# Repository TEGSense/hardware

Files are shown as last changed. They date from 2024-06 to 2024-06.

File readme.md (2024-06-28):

# TEG Sense Board

This is a thermoelectric generator (TEG) boost converter used to power a connected battery or capacitor to periodically operate a microcontroller reading from a biometric sensor to compute blood oxygen saturation. That was a big sentence!

This is the board version used in the published paper, revision 3 of the rigid prototypes.
It is used in conjunction with the [SpO2 board](https://github.com/TEGSense/hardware-spo2).
The board has a few bugs, so it's recommended to start with the [flex version](https://github.com/TEGSense/hardware-flex), even if you're not going to use a flex PCB.

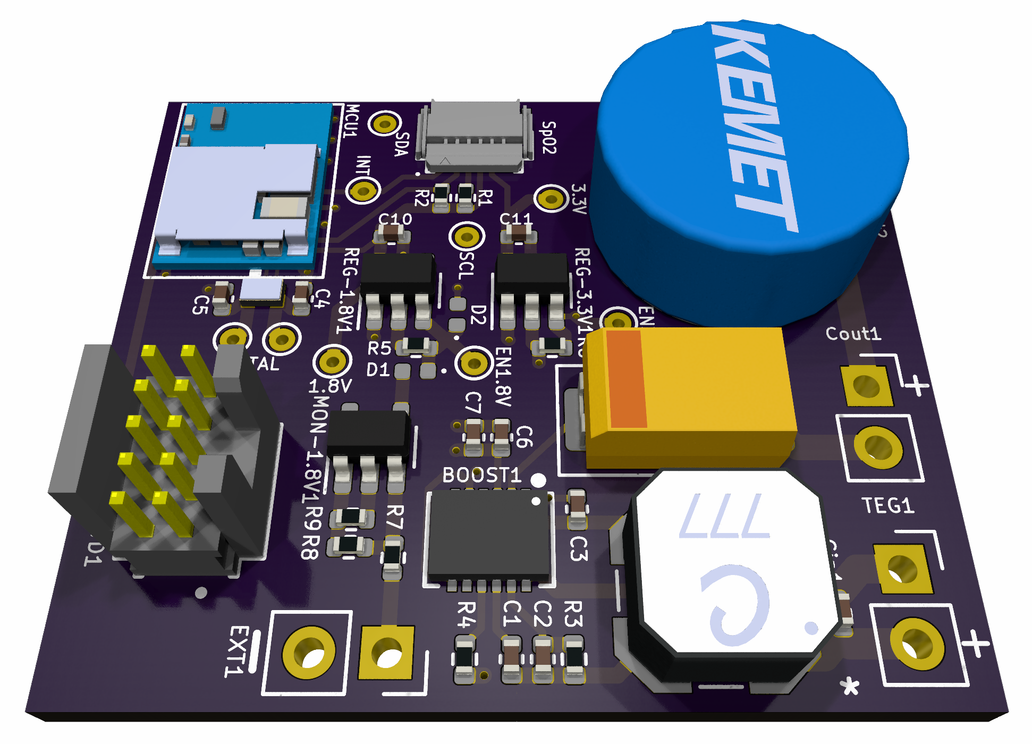
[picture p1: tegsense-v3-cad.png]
CAD rendering


## License

Shield: [][cc-by-sa]

This work is licensed under a
[Creative Commons Attribution-ShareAlike 4.0 International License][cc-by-sa].

[][cc-by-sa]

[cc-by-sa]: http://creativecommons.org/licenses/by-sa/4.0/
[cc-by-sa-image]: https://licensebuttons.net/l/by-sa/4.0/88x31.png
[cc-by-sa-shield]: https://img.shields.io/badge/License-CC%20BY--SA%204.0-lightgrey.svg

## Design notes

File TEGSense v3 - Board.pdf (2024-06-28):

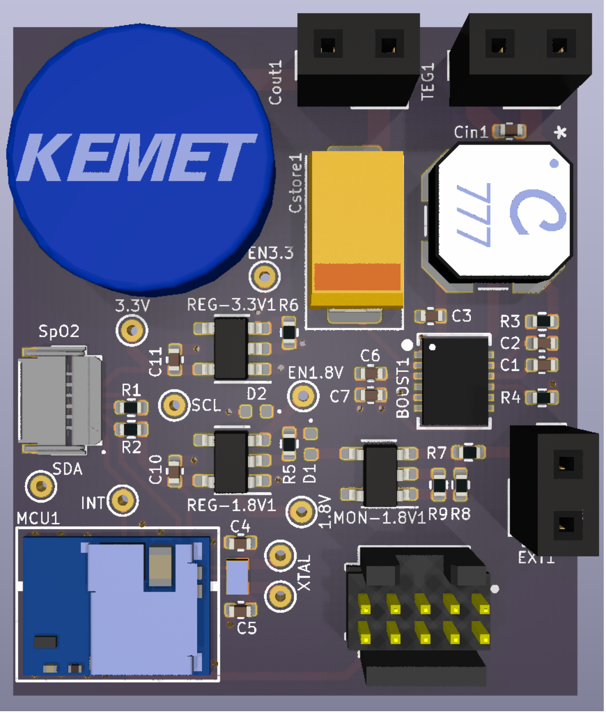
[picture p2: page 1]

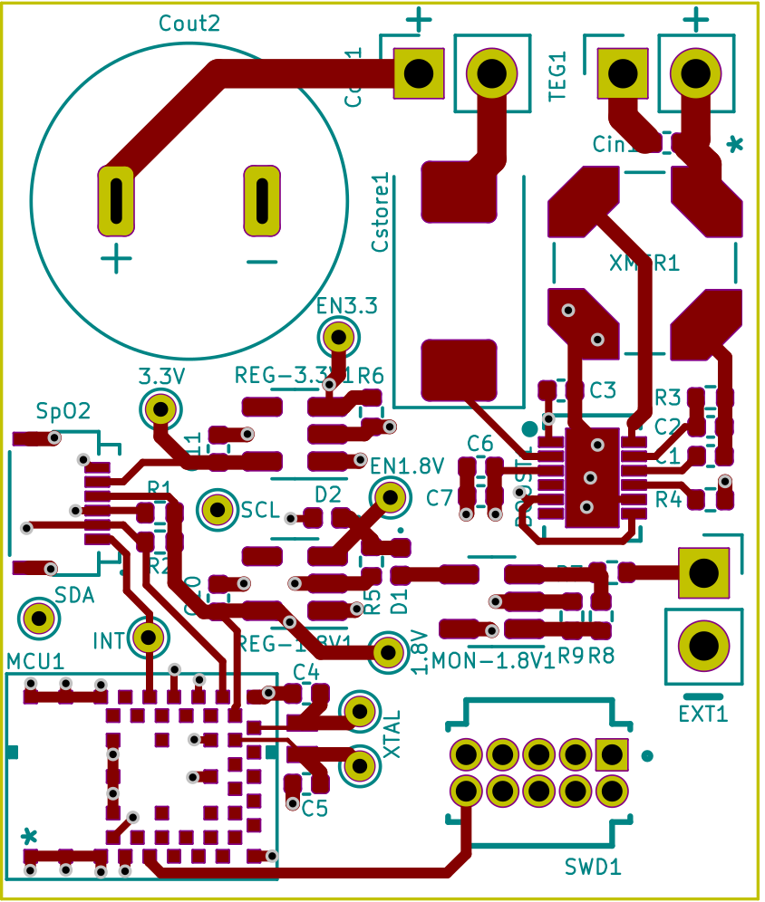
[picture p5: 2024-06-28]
TEGSense v3 - PCB Top.png

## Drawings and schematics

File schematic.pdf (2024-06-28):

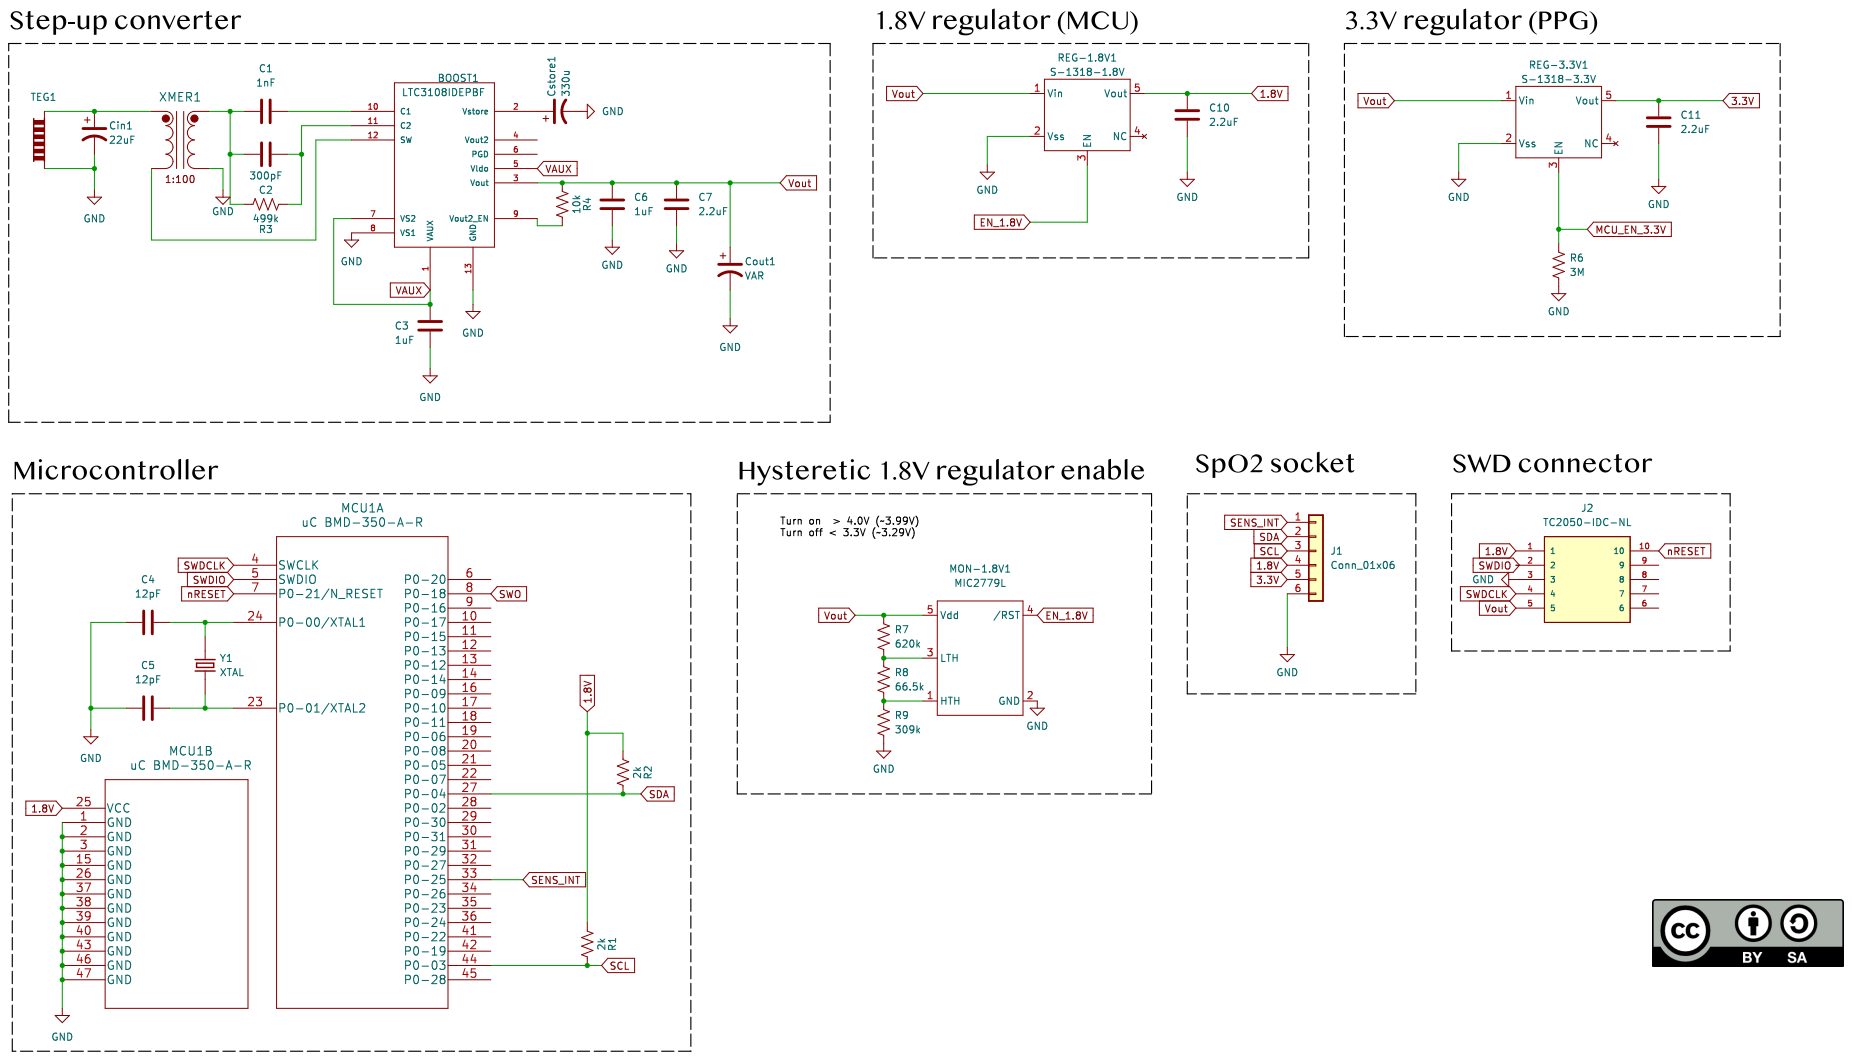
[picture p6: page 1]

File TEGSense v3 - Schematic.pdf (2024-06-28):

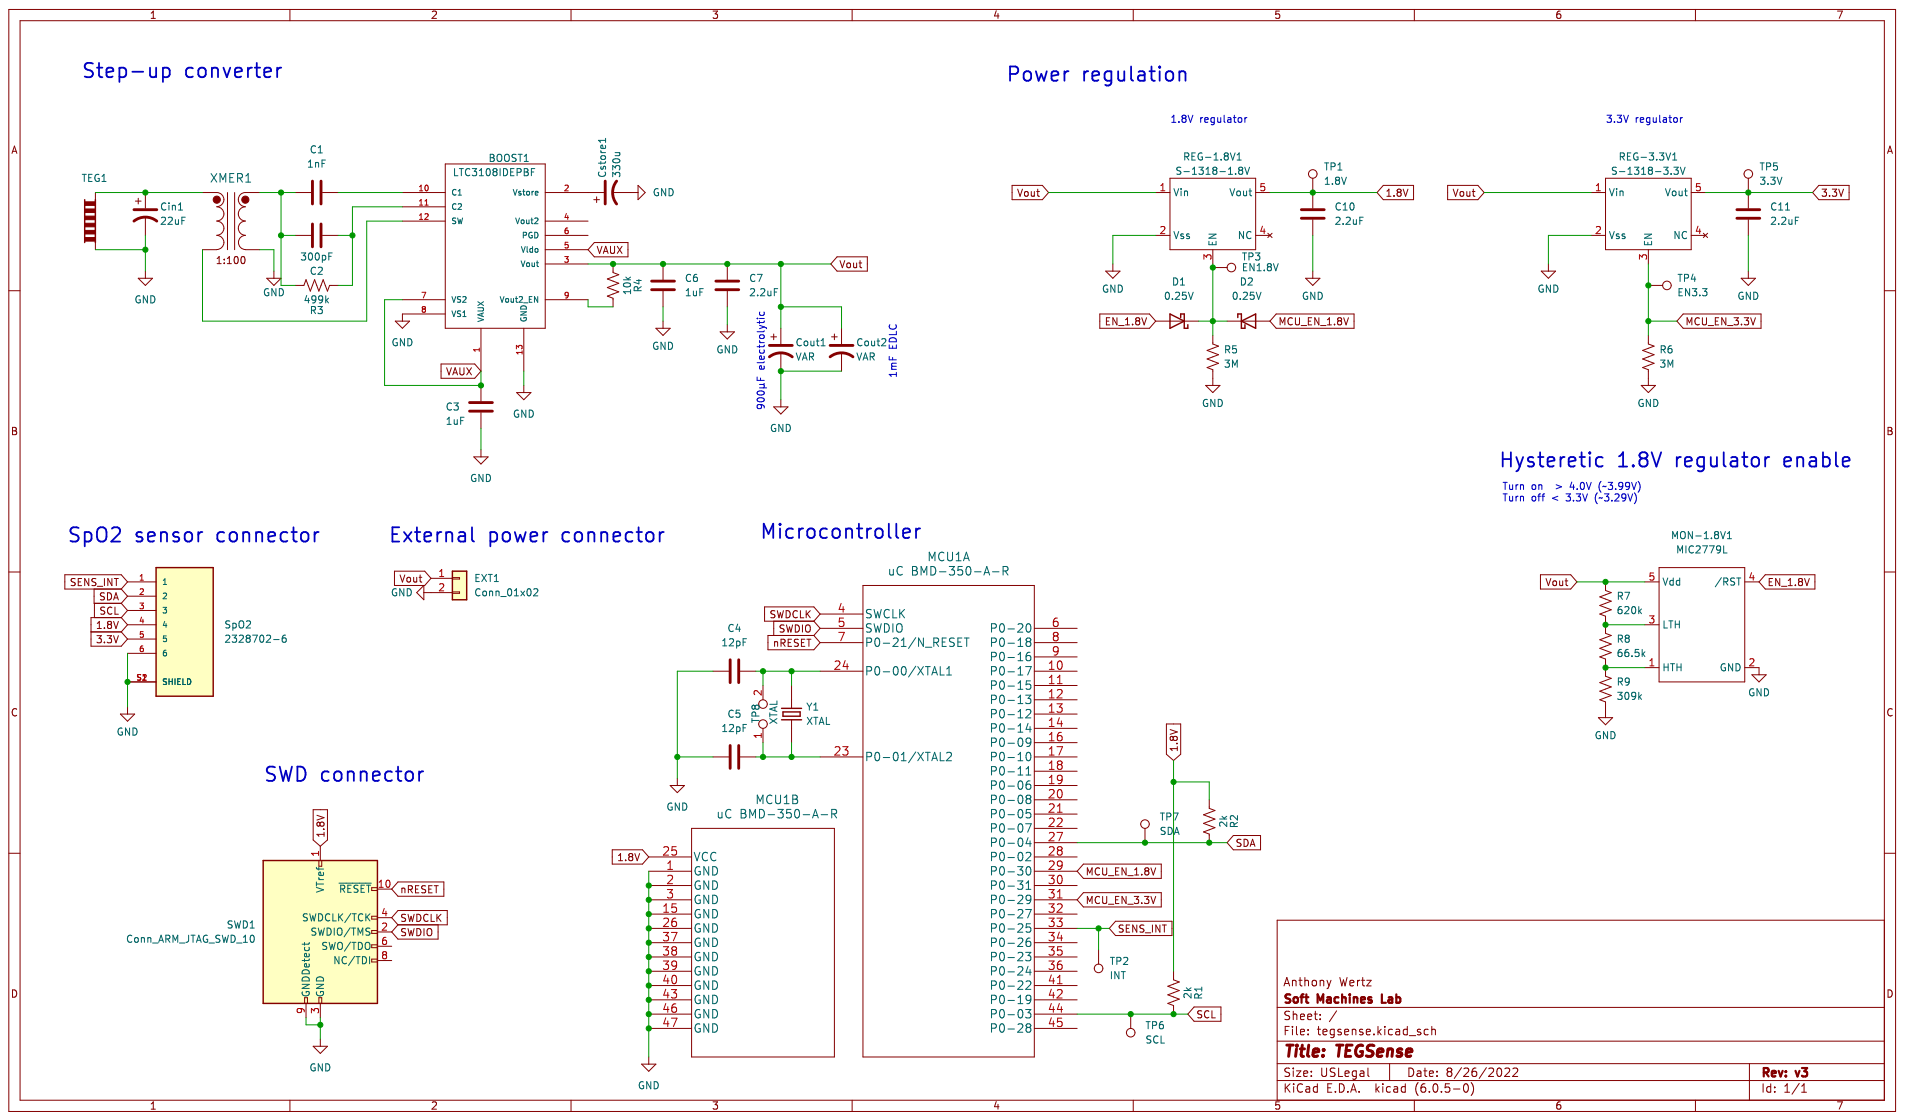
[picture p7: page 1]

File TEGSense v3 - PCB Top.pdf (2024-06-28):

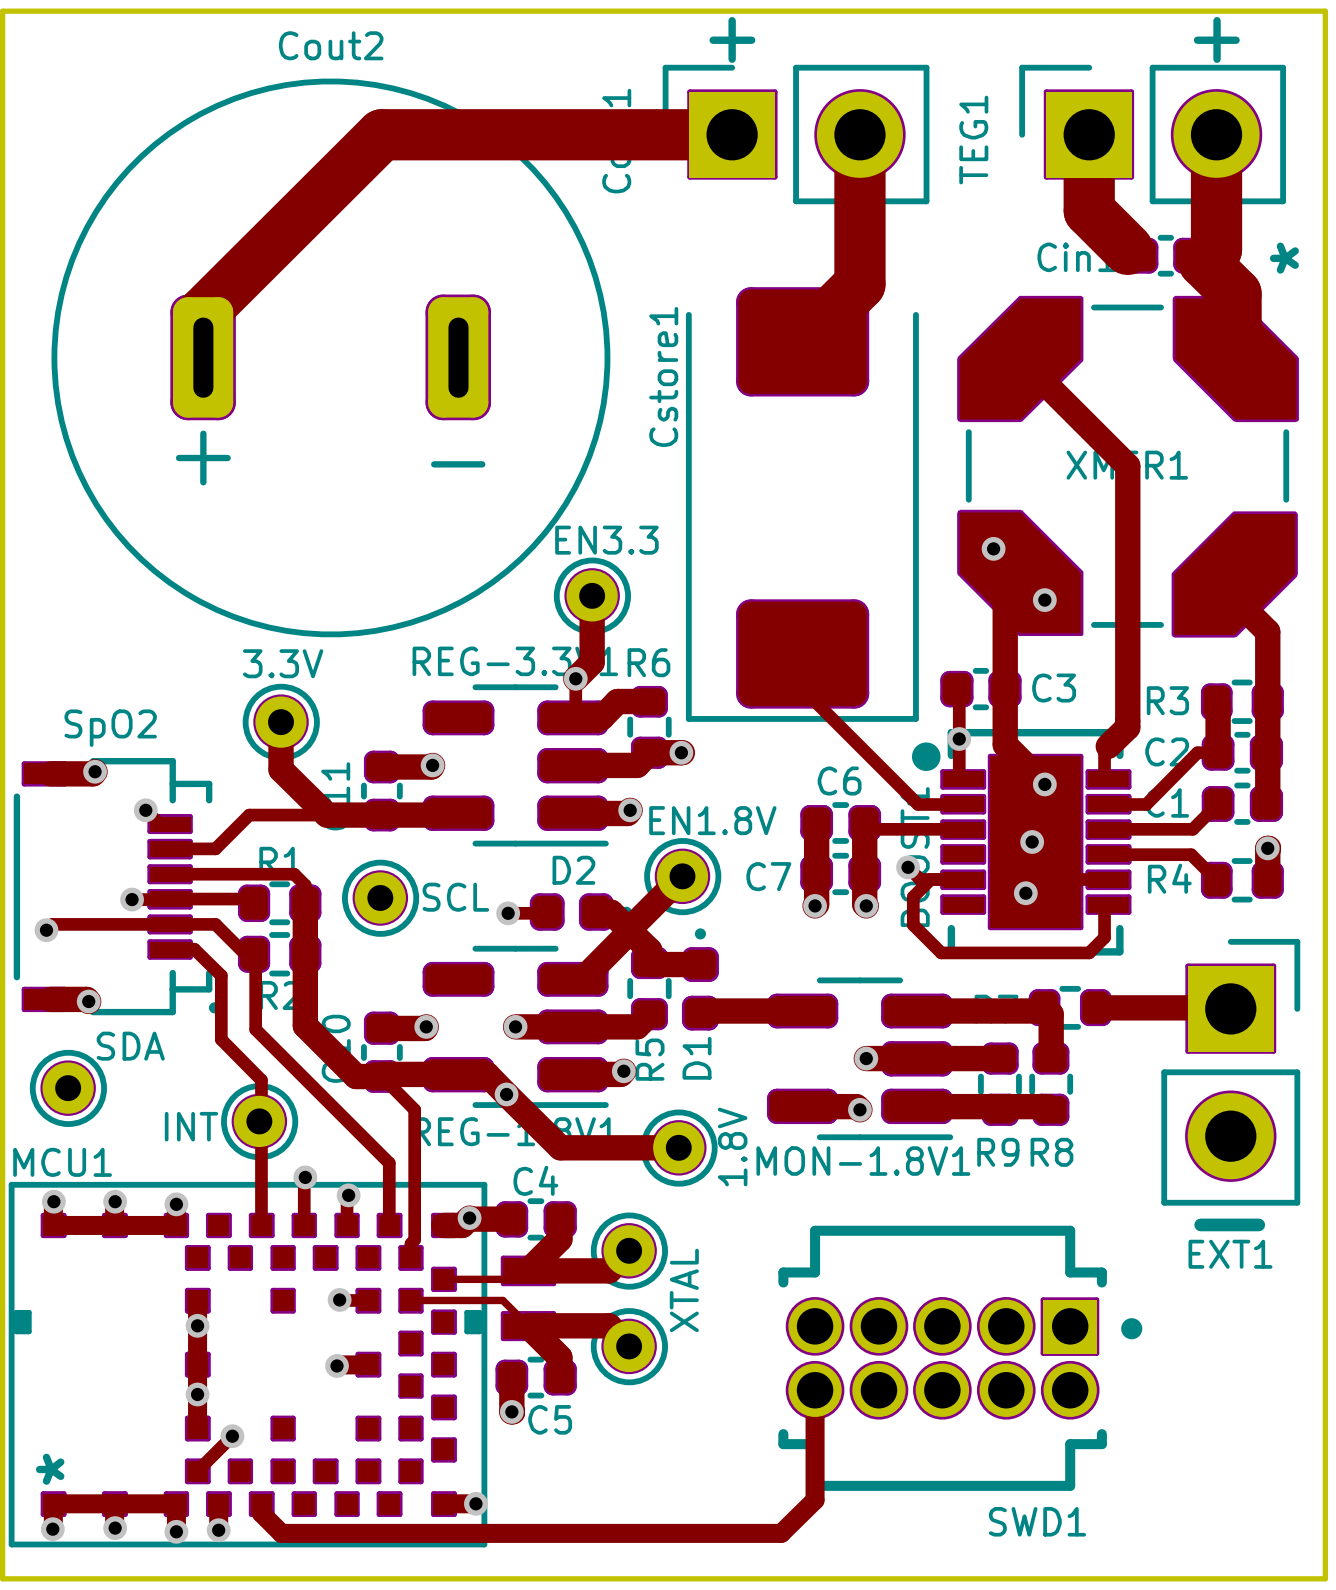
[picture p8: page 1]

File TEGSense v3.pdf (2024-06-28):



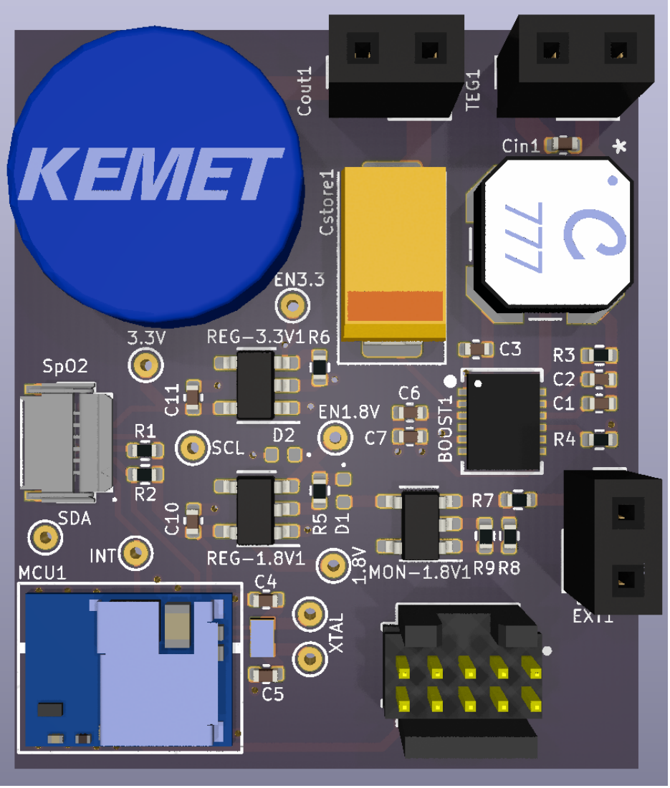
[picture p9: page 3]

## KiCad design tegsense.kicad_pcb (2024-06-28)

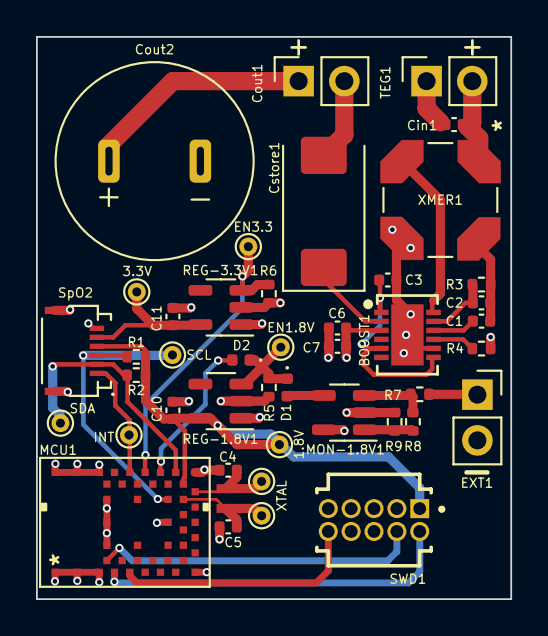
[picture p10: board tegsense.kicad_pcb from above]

Board: 4 copper layers, 26.4 x 31.2 mm, 43 parts (0 on the bottom side), 26 nets.

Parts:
BOOST1: LTC3108IDEPBF; DFN-12_DE
C1: 1nF; C_0402_1005Metric
C2: 300pF; C_0402_1005Metric
C3, C6: 1uF; C_0402_1005Metric
C4, C5: 12pF; C_0402_1005Metric
C7, C10, C11: 2.2uF; C_0402_1005Metric
Cin1: 22uF; C_0402_1005Metric
Cout1: VAR; PinSocket_1x02_P2.54mm_Vertical
Cout2: VAR; KEMET_FY_Supercap
Cstore1: 330u; CP_EIA-7343-31_Kemet-D
D1, D2: 0.25V; D_0402_1005Metric
EXT1: Conn_01x02; PinSocket_1x02_P2.54mm_Vertical
MCU1: uC BMD-350-A-R; BMD-350-A-R
MON-1.8V1: MIC2779L; SOT-23-5
R1, R2: 2k; R_0402_1005Metric
R3: 499k; R_0402_1005Metric
R4: 10k; R_0402_1005Metric
R5, R6: 3M; R_0402_1005Metric
R7: 620k; R_0402_1005Metric
R8: 66.5k; R_0402_1005Metric
R9: 309k; R_0402_1005Metric
REG-1.8V1: S-1318-1.8V; SOT-23-5
REG-3.3V1: S-1318-3.3V; SOT-23-5
SWD1: Conn_ARM_JTAG_SWD_10; SAMTEC_FTSH-105-01-F-D-K
SpO2: 2328702-6; TE_2328702-6
TEG1: TEG; PinSocket_1x02_P2.54mm_Vertical
TP1: 1.8V; TestPoint_THTPad_D1.0mm_Drill0.5mm
TP2: INT; TestPoint_THTPad_D1.0mm_Drill0.5mm
TP3: EN1.8V; TestPoint_THTPad_D1.0mm_Drill0.5mm
TP4: EN3.3; TestPoint_THTPad_D1.0mm_Drill0.5mm
TP5: 3.3V; TestPoint_THTPad_D1.0mm_Drill0.5mm
TP6: SCL; TestPoint_THTPad_D1.0mm_Drill0.5mm
TP7: SDA; TestPoint_THTPad_D1.0mm_Drill0.5mm
TP8: XTAL; TestPoint_THTPad_2x_D1.0mm_Drill0.5mm
XMER1: LPR6235-752SMLC
Y1: XTAL; XTAL_ECS-.327-9-16-TR

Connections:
1.8V: C10.1, MCU1.25 (VCC), R1.1, R2.1, REG-1.8V1.5 (Vout), SWD1.1 (VTref), SpO2.4, TP1.1
3.3V: C11.1, REG-3.3V1.5 (Vout), SpO2.5, TP5.1
EN_1.8V: D1.2 (A), MON-1.8V1.4 (/RST)
GND: BOOST1.8 (VS1), BOOST1.13 (GND), C3.2, C4.1, C5.1, C6.1, C7.2, C10.2, C11.2, Cin1.2, Cout1.2, Cout2.2, Cstore1.2, EXT1.2, MCU1.1 (GND), MCU1.2 (GND), MCU1.3 (GND), MCU1.15 (GND), MCU1.26 (GND), MCU1.37 (GND), MCU1.38 (GND), MCU1.39 (GND), MCU1.40 (GND), MCU1.43 (GND), MCU1.46 (GND), MCU1.47 (GND), MON-1.8V1.2 (GND), R5.2, R6.2, R9.2, REG-1.8V1.2 (Vss), REG-3.3V1.2 (Vss), SWD1.3 (GND), SWD1.5 (GND), SWD1.9 (GNDDetect), SpO2.6, SpO2.S1 (SHIELD), SpO2.S2 (SHIELD), TEG1.1, XMER1.3
MCU_EN_1.8V: D2.2 (A), MCU1.29 (P0-30)
MCU_EN_3.3V: MCU1.31 (P0-29), R6.1, REG-3.3V1.3 (EN), TP4.1
unnamed: BOOST1.12 (SW), XMER1.2
unnamed: C1.1, C2.1, R3.1, XMER1.4
unnamed: BOOST1.10 (C1), C1.2
unnamed: BOOST1.11 (C2), C2.2, R3.2
unnamed: C4.2, MCU1.24 (P0-00/XTAL1), TP8.2, Y1.2
unnamed: C5.2, MCU1.23 (P0-01/XTAL2), TP8.1, Y1.1
unnamed: Cin1.1, TEG1.2, XMER1.1
unnamed: BOOST1.2 (Vstore), Cstore1.1
unnamed: D1.1 (K), D2.1 (K), R5.1, REG-1.8V1.3 (EN), TP3.1
unnamed: BOOST1.9 (Vout2_EN), R4.2
unnamed: MON-1.8V1.3 (LTH), R7.2, R8.1
unnamed: MON-1.8V1.1 (HTH), R8.2, R9.1
SCL: MCU1.44 (P0-03), R1.2, SpO2.3, TP6.1
SDA: MCU1.27 (P0-04), R2.2, SpO2.2, TP7.1
SENS_INT: MCU1.33 (P0-25), SpO2.1, TP2.1
SWDCLK: MCU1.4 (SWCLK), SWD1.4 (SWDCLK/TCK)
SWDIO: MCU1.5 (SWDIO), SWD1.2 (SWDIO/TMS)
VAUX: BOOST1.1 (VAUX), BOOST1.5 (Vldo), BOOST1.7 (VS2), C3.1
Vout: BOOST1.3 (Vout), C6.2, C7.1, Cout1.1, Cout2.1, EXT1.1, MON-1.8V1.5 (Vdd), R4.1, R7.1, REG-1.8V1.1 (Vin), REG-3.3V1.1 (Vin)
nRESET: MCU1.7 (P0-21/N_RESET), SWD1.10 (~RESET)
